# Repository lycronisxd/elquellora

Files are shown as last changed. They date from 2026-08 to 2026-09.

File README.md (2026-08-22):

<h3 align="center">
<picture>
  <source media="(prefers-color-scheme: dark)" srcset="images/elquellora_title_white.png">
  <source media="(prefers-color-scheme: light)" srcset="images/elquellora_title_black.png">
  
</picture><br \>
<picture>
  <source media="(prefers-color-scheme: dark)" srcset="images/author_white.png">
  <source media="(prefers-color-scheme: light)" srcset="images/author_black.png">
  
</picture>
<br \>
a lil hackpad based off the design of ulquiorra from bleach!<br \>
designed for stardance, hack club.<br \>
<br \>
<div align="center">
    
  
  
  
  
  
  

</div>
<hr>
<h3 align="left">get started.</h3>
<h4 align="left">
<a href="instructions.md">click here</a> to go to the instructions on how to get started!
</h4>
<hr>
<h3 align="left">about the board.</h3>
<h4 align="left">
el que llora is a 4 key hackpad with pcb art made by me,<br \>
designed with inspiration and quotes from<br \>
ulquiorra cifer from bleach!<br \>
<br \>
i wanted to make a project based off of bleach for a while<br \>
(you can probably tell by my other project <a href="https://github.com/lycronisxd/peroxide">peroxide</a>)<br \>
but finally thought of a design that would look cool in practice, so here we are!
</h4>

<hr>

<h3 align="left">features of the board.</h3>
<h4 align="left">
<ul>
<li>xiao rp2040 based</li>
<li>0.91 inch oled display</li>
<li>4x mechanical keys</li>
<li>2x ec11 rotary encoders</li>
<li>6x sk6812mini-e leds (not per-key rgb though)</li>
<li>custom bleach-inspired pcb art</li>
<li>bare-pcb design</li>
</ul>
</h4>

<hr>

<h3 align="left">design images.</h3>
<h4 align="center">
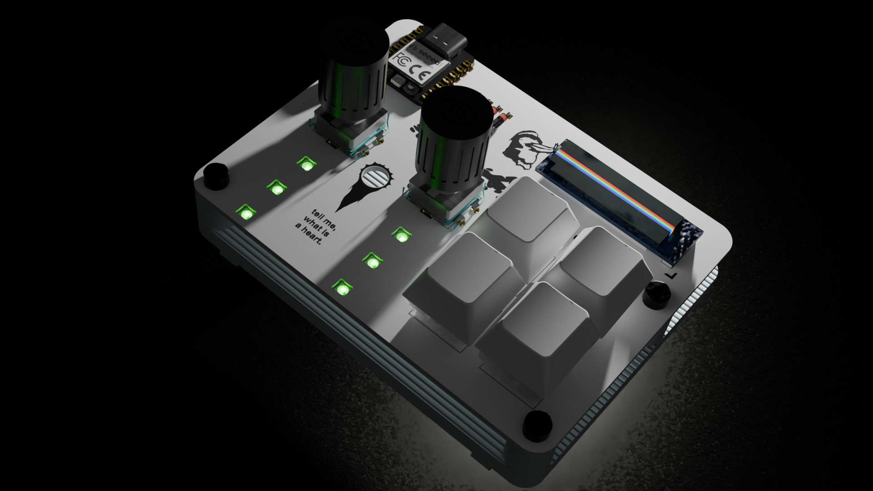
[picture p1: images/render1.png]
<br \>
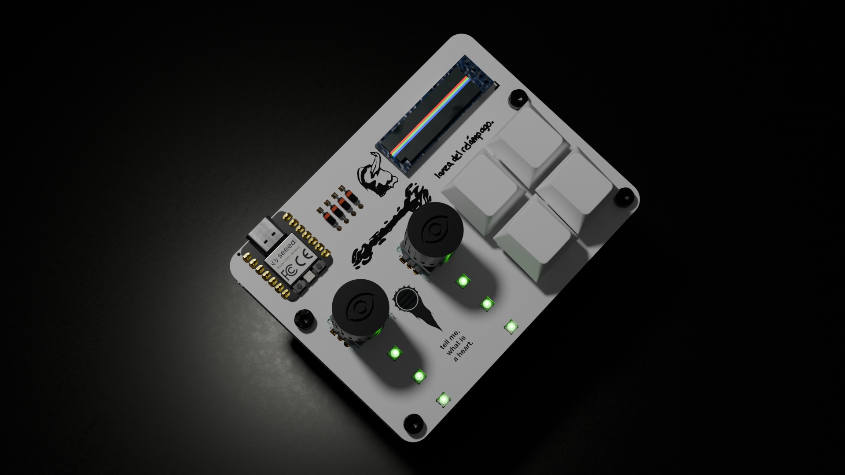
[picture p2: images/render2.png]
<br \>
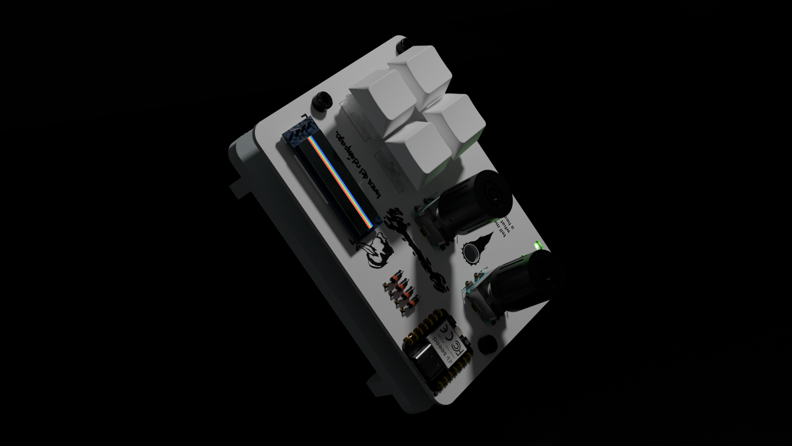
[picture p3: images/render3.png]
<br \>
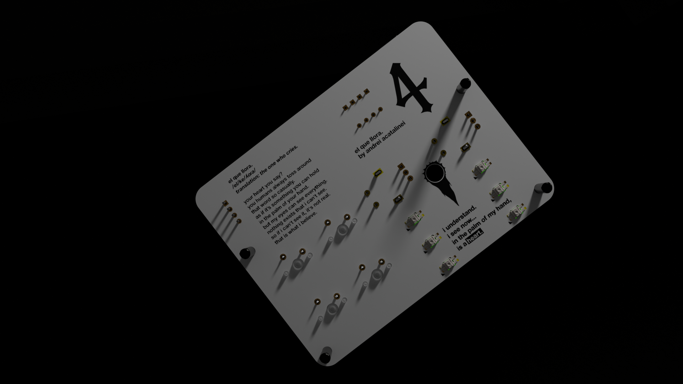
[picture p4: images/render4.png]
<br \>
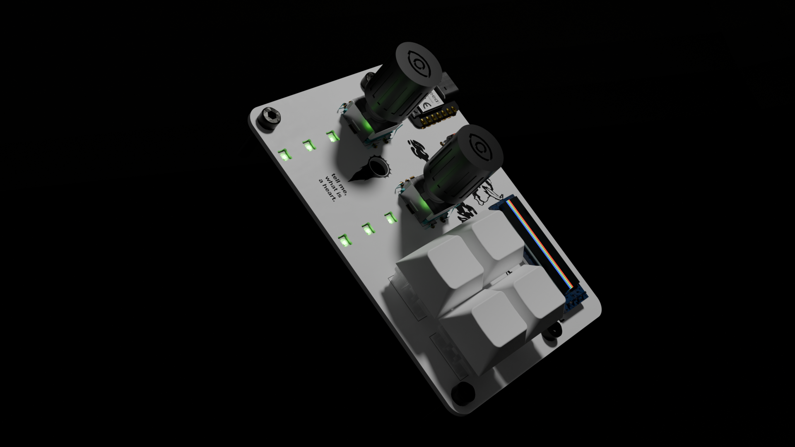
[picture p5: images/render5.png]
<br \>
<br \>

</h4>

<hr>

<h3 align="left">bill of materials.</h3>

|item no.|part no.|part name |qty.|supplier |unit cost|total cost|notes |
|---|---|---|----|---|---|---|---|
|1 |PCB-001 |elquellora pcb |5 |jlcpcb | $0.40 | $7.19 |$2 for 5 pcbs + $5.12 for shipping |
|2 |PCB-002 |seeed studio xiao rp2040  |1 |hack club |N/A |N/A |provided in hackpad kit |
|3 |PCB-003 |1n4148 diodes |4 |hack club |N/A |N/A |provided in hackpad kit |
|4 |PCB-004 |0.91 inch oled |1 |hack club |N/A |N/A |provided in hackpad kit |
|5 |PCB-005 |ec11 rotary encoders |2 |hack club |N/A |N/A |provided in hackpad kit |
|6 |PCB-006 |sk6812 mini-e leds |6 |hack club |N/A |N/A |provided in hackpad kit |
|7 |PCB-007 |mx style switches |4 |hack club |N/A |N/A |provided in hackpad kit |
|8 |3D-001  |m3x5mmx4mm heatset inserts|4 |hack club |N/A |N/A |provided in hackpad kit |
|9 |3D-002  |m3x16mm screws |4 |hack club |N/A |N/A |provided in hackpad kit |
|10 |3D-003  |3d printed case |1 |print legion|? |? |will update when receiving a quote from a printer|
|11 |3D-004  |3d printed encoder knobs  |2 |print legion|? |? |will update when receiving a quote from a printer|


<hr>

<h3 align="left">my other stuff.</h3>
<h4 align="left">
a custom rp2040 dev board, <a href="https://github.com/lycronisxd/peroxide">peroxide</a><br \>
<br \>
an 18 key, per key rgb macropad with an oled screen, <a href="https://github.com/lycronisxd/pentoxide">pentoxide</a><br \>
<br \>
a custom sim-racing shifter, <a href="https://github.com/lycronisxd/a-shift">a-shift</a><br \>
<br \>
a custome corexy 3d printer, <a href="https://github.com/lycronisxd/https://github.com/lycronisxd/polylactic">polylactic</a><br \>
<br \>
a handwired split mechanical keyboard, <a href="https://github.com/lycronisxd/e-split">e-split</a>
</h4>

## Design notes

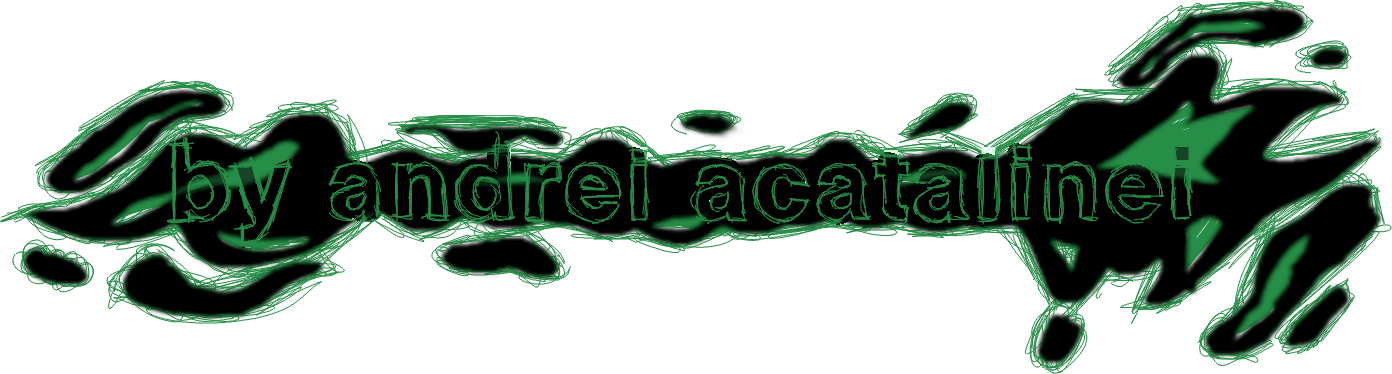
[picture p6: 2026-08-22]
images/author_black.png

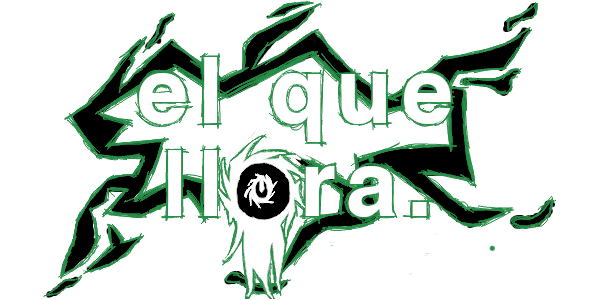
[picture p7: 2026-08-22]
images/elquellora_title_white.png

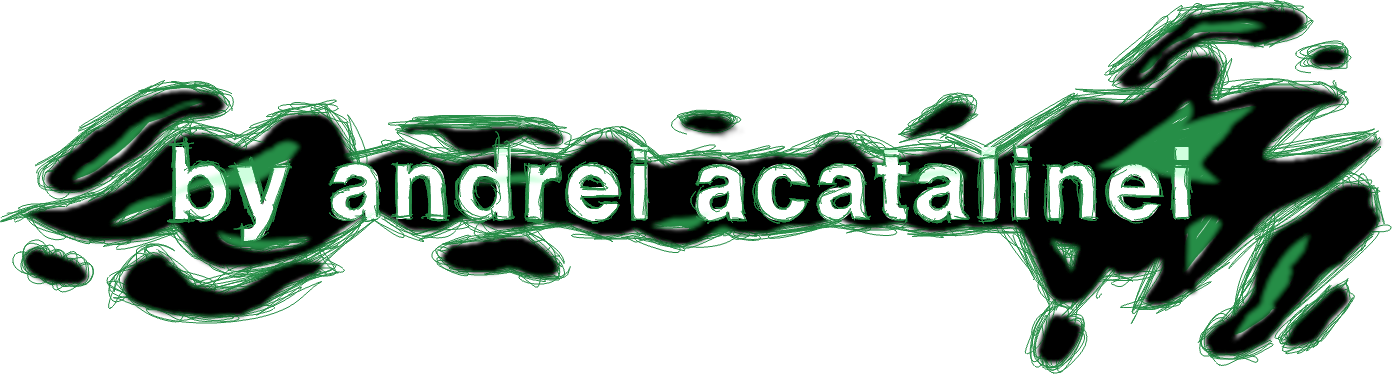
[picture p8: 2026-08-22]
images/author_white.png

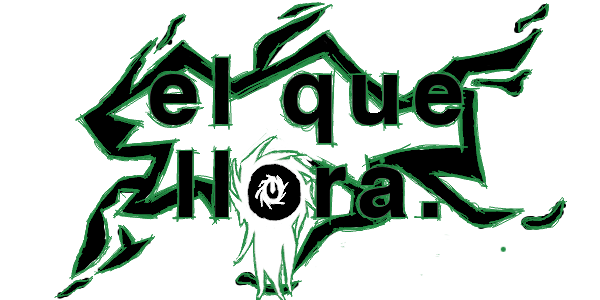
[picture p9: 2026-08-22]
images/elquellora_title_black.png

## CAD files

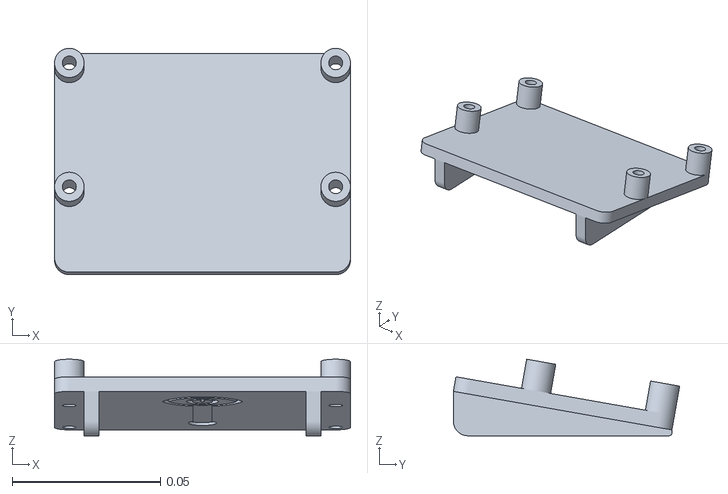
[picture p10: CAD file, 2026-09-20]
production/3d-printing/case.stl
0.1 x 0.0765 x 0.0259

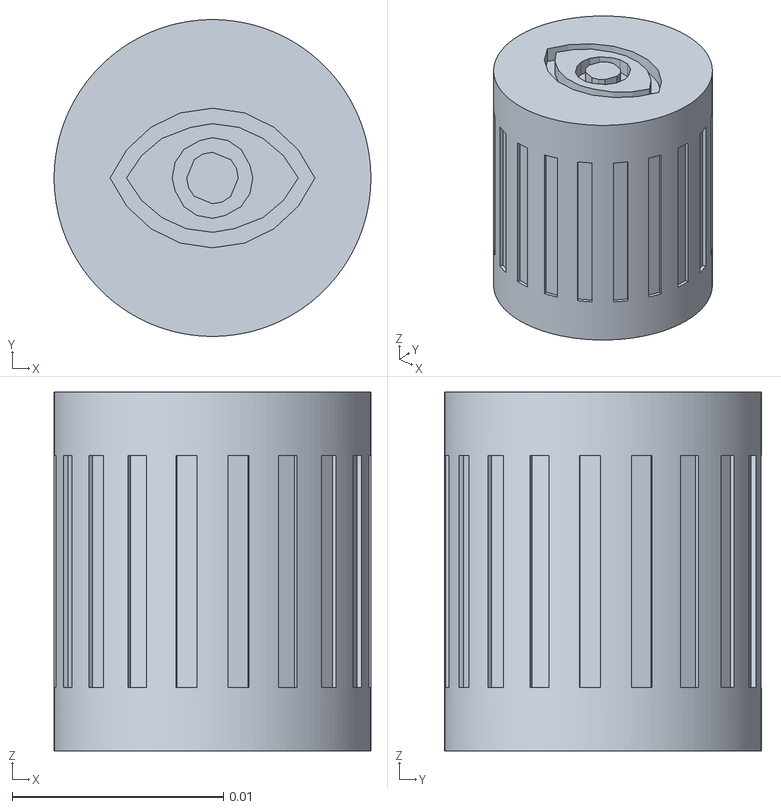
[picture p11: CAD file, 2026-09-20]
production/3d-printing/encoder cap.stl
0.015 x 0.015 x 0.017

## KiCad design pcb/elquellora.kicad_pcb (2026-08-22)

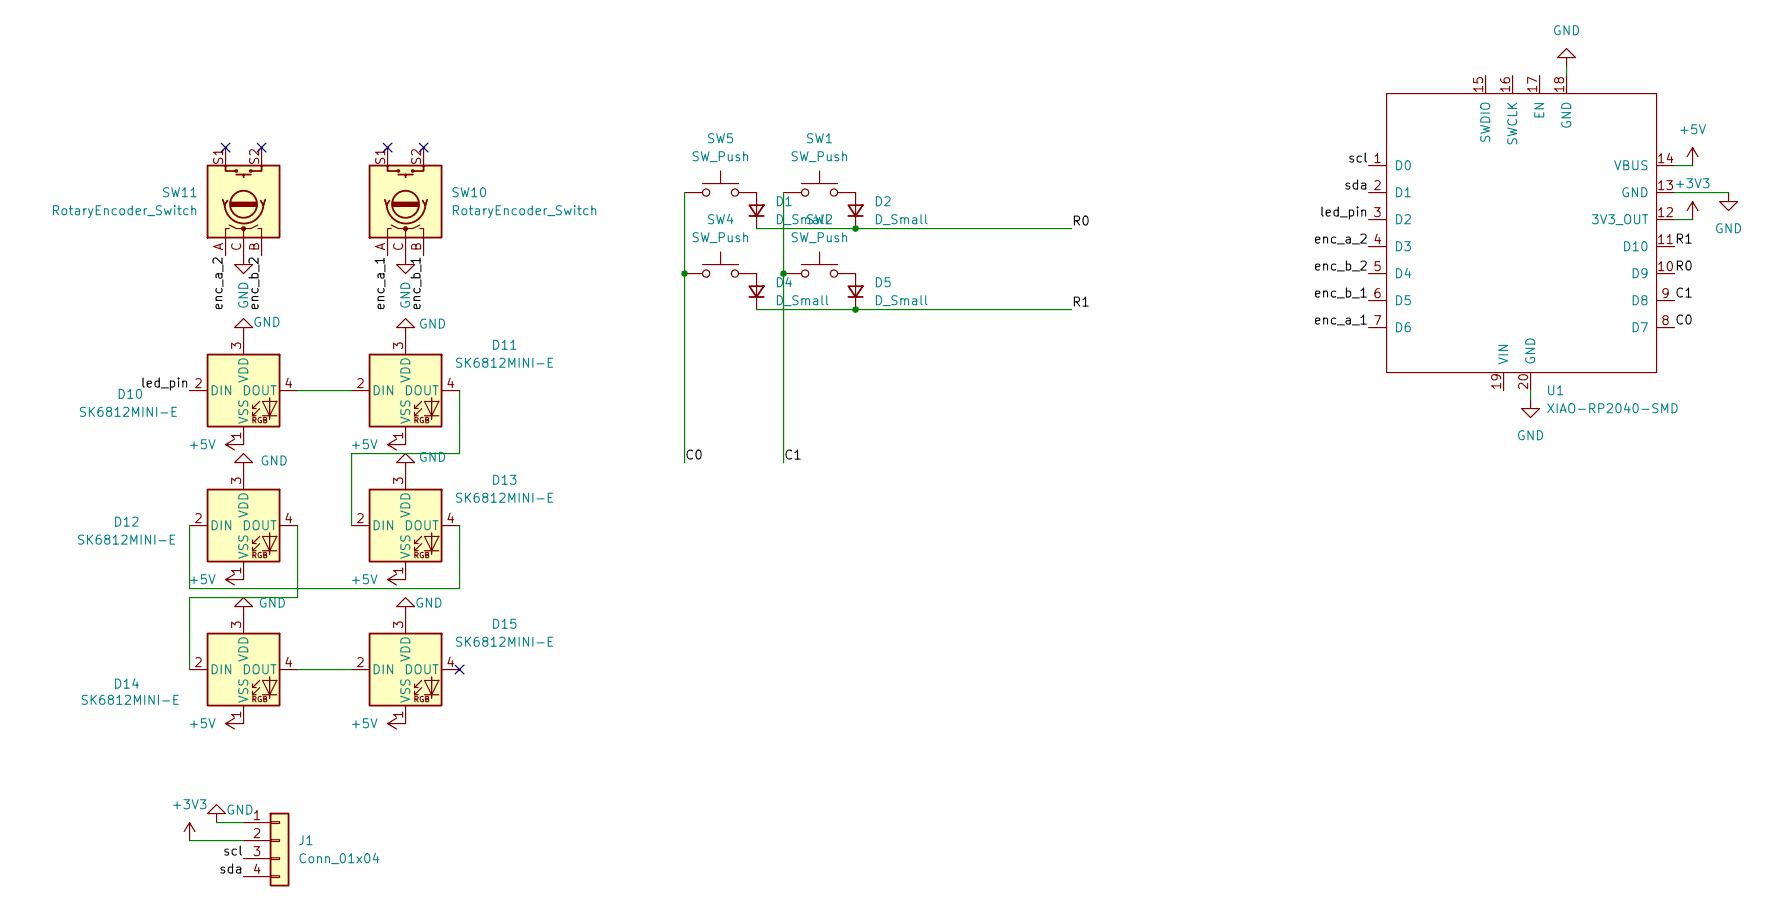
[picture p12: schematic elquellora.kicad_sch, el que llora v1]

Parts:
D1, D2, D4, D5: D_Small; Diode_DO-35
D10, D11, D12, D13, D14, D15: SK6812MINI-E; SK6812MINI-E_fixed
J1: Conn_01x04; PinHeader_1x04_P2.54mm_Vertical
SW1, SW2, SW4, SW5: SW_Push; SW_Cherry_MX_1.00u_PCB
SW10, SW11: RotaryEncoder_Switch; RotaryEncoder_Alps_EC11E-Switch_Vertical_H20mm
U1: XIAO-RP2040-SMD

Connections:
+3V3: J1.2, U1.12 (3V3_OUT)
+5V: D10.1 (VSS), D11.1 (VSS), D12.1 (VSS), D13.1 (VSS), D14.1 (VSS), D15.1 (VSS), U1.14 (VBUS)
/C0: SW4.1, SW5.1, U1.8 (D7)
/C1: SW1.1, SW2.1, U1.9 (D8)
/R0: D1.1 (K), D2.1 (K), U1.10 (D9)
/R1: D4.1 (K), D5.1 (K), U1.11 (D10)
/enc_a_1: SW10.A, U1.7 (D6)
/enc_a_2: SW11.A, U1.4 (D3)
/enc_b_1: SW10.B, U1.6 (D5)
/enc_b_2: SW11.B, U1.5 (D4)
/led_pin: D10.2 (DIN), U1.3 (D2)
/scl: J1.3, U1.1 (D0)
/sda: J1.4, U1.2 (D1)
GND: D10.3 (VDD), D11.3 (VDD), D12.3 (VDD), D13.3 (VDD), D14.3 (VDD), D15.3 (VDD), J1.1, SW10.C, SW11.C, U1.13 (GND), U1.18 (GND), U1.20 (GND)
unnamed: D1.2 (A), SW5.2
unnamed: D2.2 (A), SW1.2
unnamed: D4.2 (A), SW4.2
unnamed: D5.2 (A), SW2.2
unnamed: D10.4 (DOUT), D11.2 (DIN)
unnamed: D11.4 (DOUT), D13.2 (DIN)
unnamed: D12.2 (DIN), D13.4 (DOUT)
unnamed: D12.4 (DOUT), D14.2 (DIN)
unnamed: D14.4 (DOUT), D15.2 (DIN)

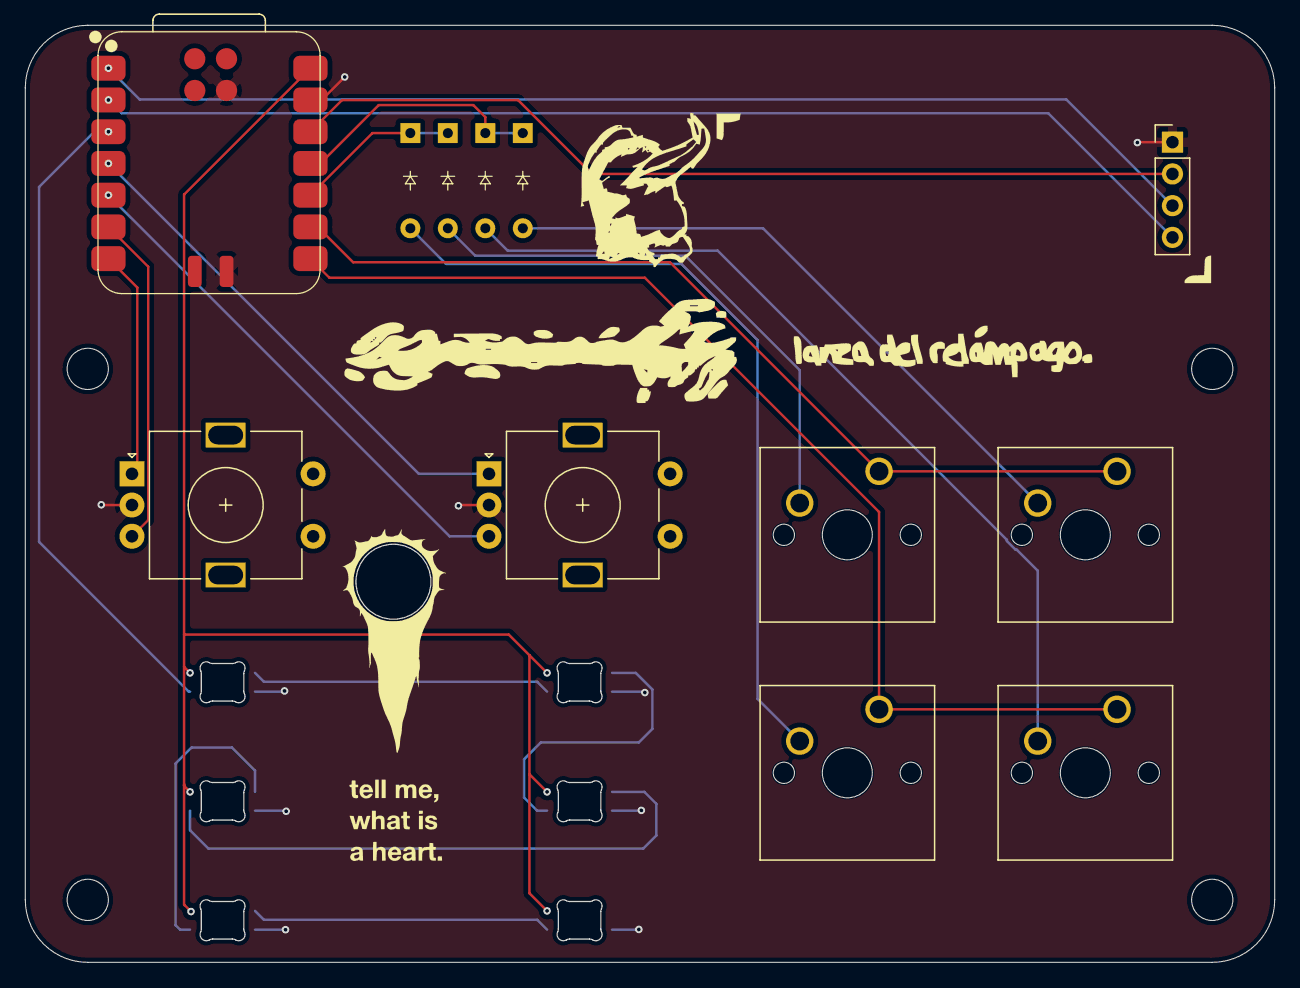
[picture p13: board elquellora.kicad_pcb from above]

Board: 2 copper layers, 100.0 x 75.0 mm, 18 parts (0 on the bottom side), 23 nets.

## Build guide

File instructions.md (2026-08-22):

<h1>instructions</h1>
<h3>parts list</h3>
<h4>3d printed parts</h4>
  <li>1 x <b>3d printed case</b></li>
  <li>2 x <b>3d printed encoder knobs</b></li>
<h4>mounting hardware</h4>
  <li>4 x <b>m3 x 16mm screws</b></li>
  <li>4 x <b>m3 x 5mm x 4mm heatset inserts</b></li>
<h4>pcbs and whatnot</h4>
  <li>1 x <b>el que llora pcb</b></li>
  <li>2 x <b>seeed studio xiao rp2040</b></li>
  <li>4 x <b>1n4148 do-35 through-hole diodes</b></li>
  <li>1 x <b>0.91-inch oled display with pinout (GND - VCC - SCL - SDA)</b></li>
  <li>2 x <b>ec11 rotary encoders</b></li>
  <li>6 x <b>sk6812 mini-e leds</b></li>
  <li>4 x <b>mx-style switches</b></li>
  <li>4 x <b>keycaps of your choice</b></li>
<hr>
<h3>assembling the pcb</h3>
<ol>
<li>position the <b>seeed studio xiao rp2040</b> onto its corresponding footprint on the front of the pcb.</li>
<li>solder each corner pad to ensure stability when soldering.</li>
<li>solder the rest of the microcontroller pads down.</li>
<br \>
<li>bend the legs of the <b>1n4148 do-35 through-hole diodes</b> to a 90 degree angle and feed them through the corresponding diode holes on the front of the pcb with the red band facing upwards.</li>
<li>solder the diodes down from the back of the pcb.</li>
<br \>
<li>solder a 4-pin header onto the <b>0.91-inch oled display</b> with the short end going up the back of the display's pcb.</li>
<li>solder the short end of the header from the top of the display's pcb.</li>
<li>slot the long end of the header through the corresponding footprint on the pcb with the display facing towards the microcontroller.</li>
<li>solder the header down from the back of the pcb.</li>
<br \>
<li>slot the <b>ec11 rotary encoders</b> in through their corresponding footprints on the front of the pcb.</li>
<li>solder the pins down from the back of the pcb.</li>
<br \>
<li>position the <b>sk6812 mini-e leds</b> on their corresponding footprints on the back of the pcb with the notched corner facing the arrow on the back of the pcb.</li>
<li>solder the leds down from the back of the pcb.</li>
<br \>
<li>position the <b>mx-style switches</b> in their corresponding footprints on the front of the pcb.</li>
<li>solder the switches down from the back of the pcb.</li>
</ol>

<h3>assembling the rest of the board</h3>
<ol>
<li>position your <b>m3 x 5mm x 4mm heatset inserts</b> over each standoff on the <b>3d printed case.</b></li>
<li>use a soldering iron to push the inserts through the standoff holes and stop when the insert is flush with the top of the standoff.</li>
<br \>
<li>position each <b>m3 x 16mm screw</b> through the holes of the completed pcb and over each standoff of the case.</li>
<li>screw the pcb down firmly.</li>
</ol>

<h3>flashing the firmware</h3>
<ol>
<li><a href="firmware/">download the firmware</a> from the github repo.</li>
<br \>
<li>hold the boot button on the <b>seeed studio xiao rp2040 and plug in a usb-c whilst still holding the button.</b></li>
<li>release the button when the device is recognised.</li>
<br \>
<li>use the file explorer of your choice to find the microcontroller acting like a usb device.</li>
<li>drag and drop the downloaded firmware onto the usb device.</li>
<br \>
<li>the firmware will flash itself from there.</li>
</ol>
<br \>
and voila, you have a macropad!

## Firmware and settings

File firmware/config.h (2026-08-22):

#define WS2812_DI_PIN GP28
#define RGBLIGHT_LED_COUNT 6
#define ENCODER_A_PINS { GP0, GP29 }
#define ENCODER_B_PINS { GP7, GP6 }

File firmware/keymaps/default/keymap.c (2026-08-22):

// Copyright 2023 QMK
// SPDX-License-Identifier: GPL-2.0-or-later

#include QMK_KEYBOARD_H

const uint8_t led_sequence[6] = {0, 3, 4, 1, 2, 5};

uint16_t anim_timer = 0;
uint8_t current_step = 0;

void matrix_scan_user(void) {
    if 
    (timer_elapsed(anim_timer) > 300) {
        anim_timer = timer_read();
        rgblight_setrgb(0, 0, 0);
        uint8_t target_led = led_sequence[current_step];
        rgblight_setrgb_at(34, 139, 34, target_led);
        current_step = (current_step + 1) % 6;
    }
}

void keyboard_post_init_user(void) {
    rgblight_enable_noeeprom();
    anim_timer = timer_read();
}

const uint16_t PROGMEM encoder_map[][NUM_ENCODERS][NUM_DIRECTIONS] = {
    [0] = { ENCODER_CCW_CW(MS_WHLU, MS_WHLD),  ENCODER_CCW_CW(KC_VOLD, KC_VOLU)  }
};

const uint16_t PROGMEM keymaps[][MATRIX_ROWS][MATRIX_COLS] = {
    [0] = LAYOUT(
        KC_A, KC_B,
        KC_C, KC_D
    )
};

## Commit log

2026-08-22 create /3d-printing
2026-08-22 create /pcb
2026-08-22 add 3d printing production files
    [elquellora_case.step, elquellora_encoder_cap.step]
2026-08-22 add pcb production file
2026-08-22 add kicad pcb files
    [elquellora.kicad_pcb, elquellora.kicad_sch]
2026-08-22 add main hackpad assembly 3d model to /cad
2026-08-22 create /production/3d-printing
2026-08-22 add kicad design files to /pcb root
    [elquellora.kicad_pcb, elquellora.kicad_sch]
2026-08-22 add 3d printing files to /production/3d-printing
    [elquellora_case.step, elquellora_encoder_cap.step]
2026-08-22 add pcb gerber to /production/gerbers
2026-08-22 add kicad prl file to /pcb
2026-09-20 added stl files instead of step
    [case.stl, encoder cap.stl]
